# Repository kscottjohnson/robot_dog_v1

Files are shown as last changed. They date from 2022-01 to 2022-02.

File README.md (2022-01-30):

# robot_dog_v1

Robot Dog built with 

Adafruit Feather nRF52840 Sense
https://www.adafruit.com/product/4516

Adafruit 16-Channel 12-bit PWM/Servo Driver
https://www.adafruit.com/product/815

Adafruit PowerBoost 1000
https://www.adafruit.com/product/2465

Adafruit FeatherWing OLED - 128x64 OLED
https://www.adafruit.com/product/4650

Inspired by James Bruton's Mini Robot Dog
https://www.youtube.com/watch?v=DfBF26DaT-M

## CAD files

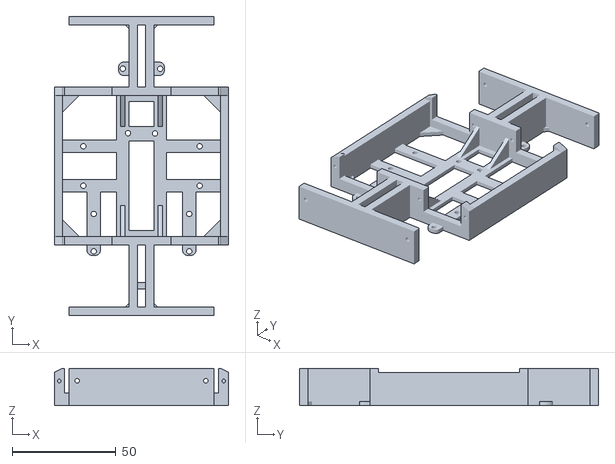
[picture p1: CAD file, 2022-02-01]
stl/chassis.stl
84.0 x 144.0 x 18.0

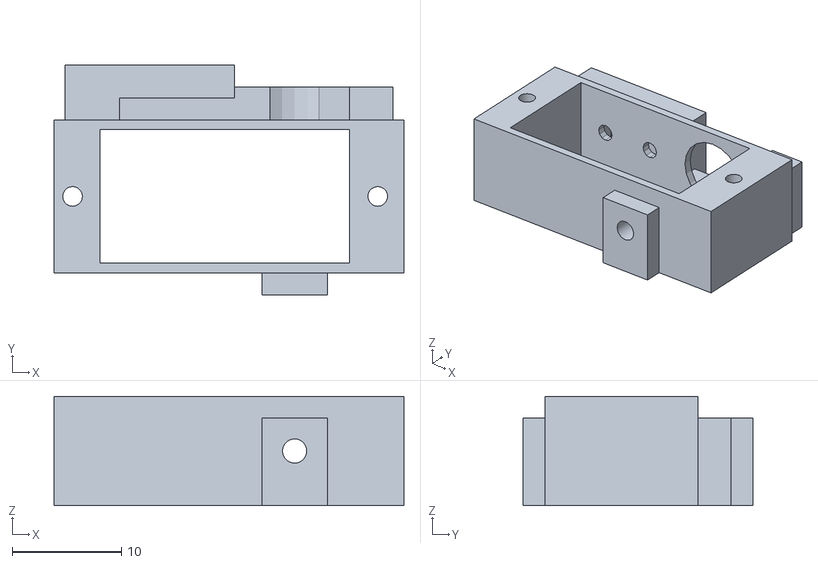
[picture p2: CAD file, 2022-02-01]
stl/shoulder.stl
32.0 x 21.0 x 10.0

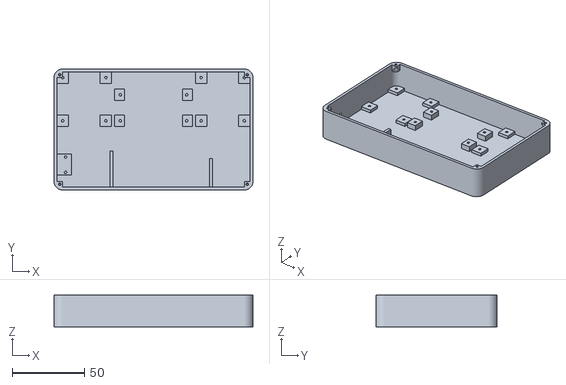
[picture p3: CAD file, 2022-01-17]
stl/remote_case.stl
138.0 x 84.0 x 22.0

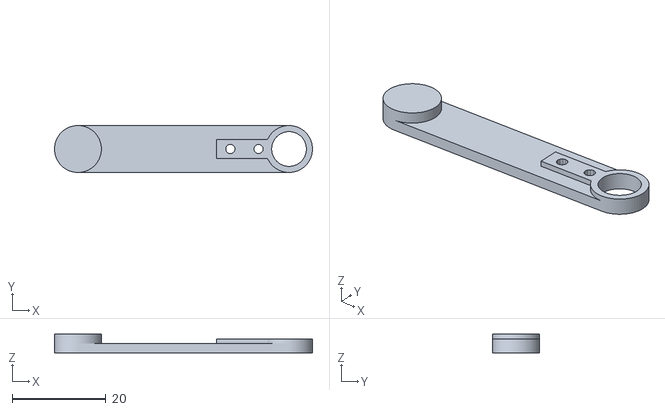
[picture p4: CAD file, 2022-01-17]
stl/leg_lower_no_foot.stl
55.0 x 10.0 x 4.00

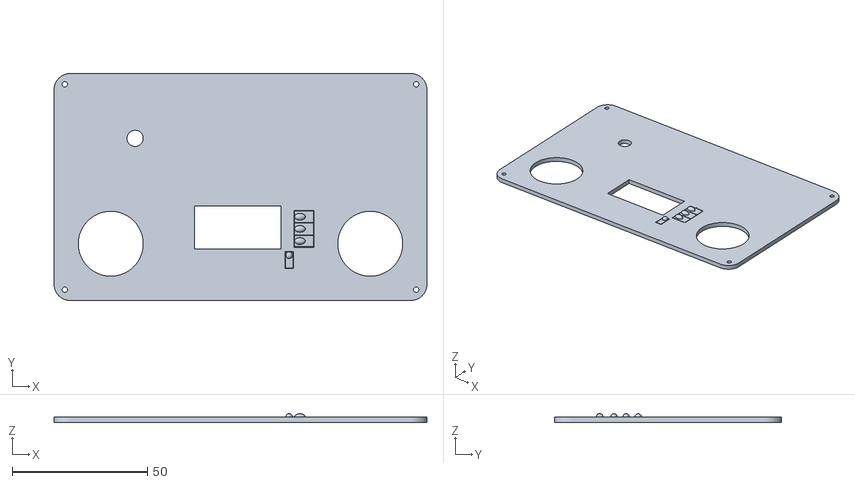
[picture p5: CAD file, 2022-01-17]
stl/remote_lid.stl
138.0 x 84.0 x 3.30

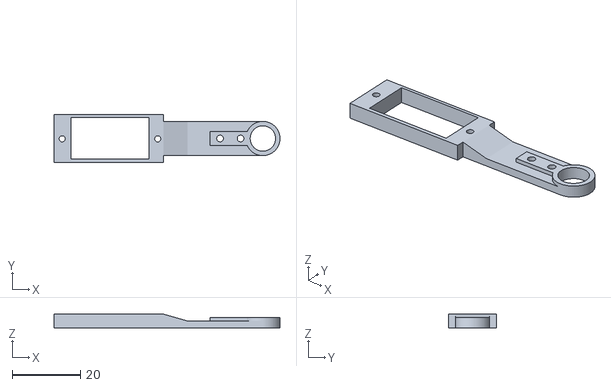
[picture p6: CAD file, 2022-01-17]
stl/leg_upper.stl
66.0 x 14.0 x 4.00

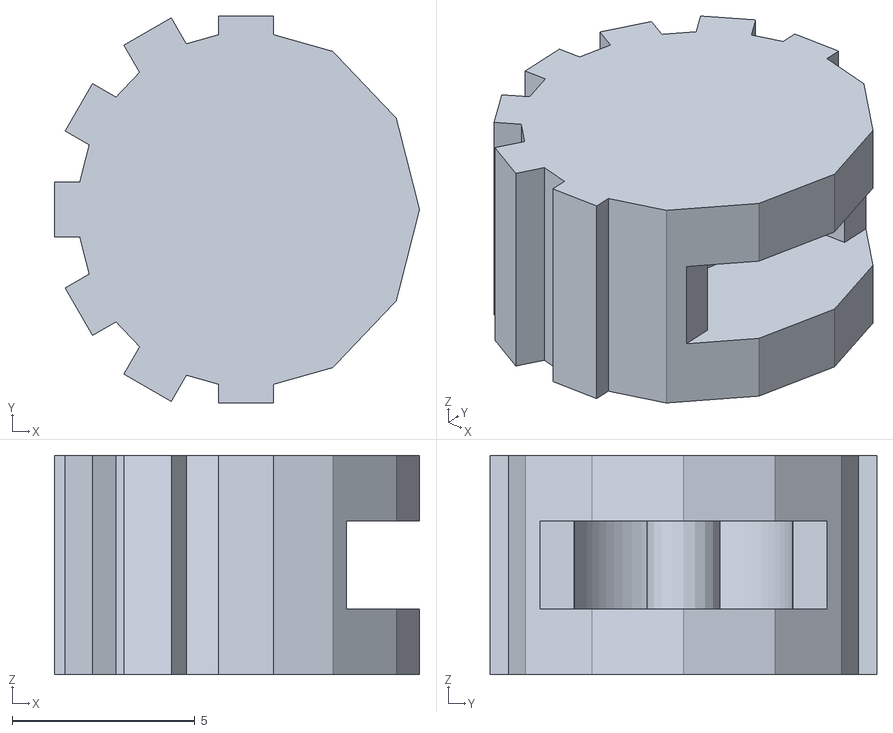
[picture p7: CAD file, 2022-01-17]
stl/foot_flex.stl
10.0 x 10.6 x 6.00

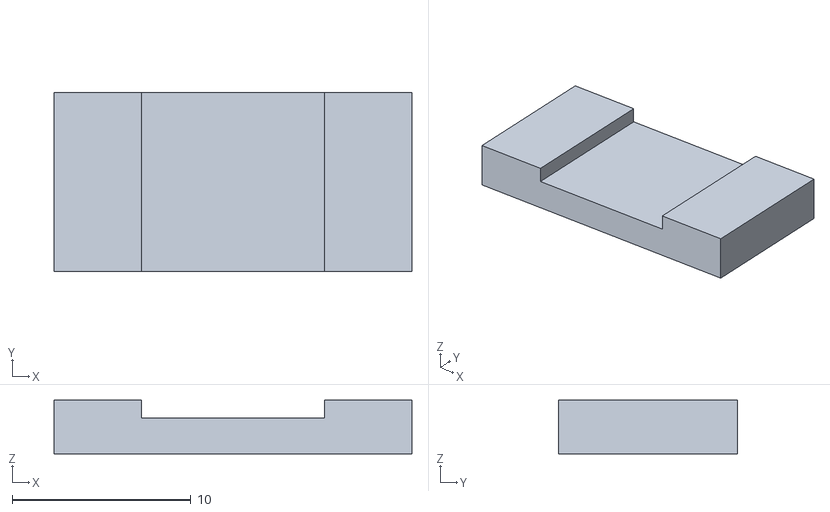
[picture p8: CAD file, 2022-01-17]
stl/leg_lower_holder.stl
20.0 x 10.0 x 3.00

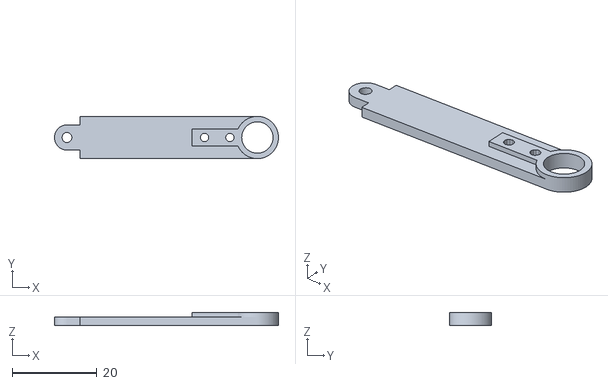
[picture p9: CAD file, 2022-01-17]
stl/leg_lower_w_foot.stl
53.0 x 10.0 x 3.00

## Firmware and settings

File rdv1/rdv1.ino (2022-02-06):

#include <SPI.h>
#include <Wire.h>
#include <Adafruit_GFX.h>
#include <Adafruit_SH110X.h>
#include <bluefruit.h>
#include <Adafruit_PWMServoDriver.h>
#include <Adafruit_LSM6DS33.h>
#include <Adafruit_LIS3MDL.h>
#include <Adafruit_Sensor_Calibration.h>
#include <Adafruit_AHRS.h>
#include "LegServo.h"

// Servos
Adafruit_PWMServoDriver driver = Adafruit_PWMServoDriver(0x40);
#define SERVO_FREQ 50

LegServo servos[12] = {  // 90 degrees 220 to 420; 
  LegServo(&driver,  0, 300, 90), // Front Right
  LegServo(&driver,  1, 243, 45),
  LegServo(&driver,  2, 273, 90),
  LegServo(&driver,  8, 298, 90), // Front Left
  LegServo(&driver,  9, 333, 135),
  LegServo(&driver, 10, 300, 90),
  LegServo(&driver,  4, 306, 90), // Back Right
  LegServo(&driver,  5, 360, 135),
  LegServo(&driver,  6, 300, 90),
  LegServo(&driver, 12, 310, 90), // Back Left
  LegServo(&driver, 13, 242, 45),
  LegServo(&driver, 14, 320, 90)
};

Leg legs[4] = {
  Leg(&servos[0], &servos[1], &servos[2], false, true, false), // Front Right
  Leg(&servos[3], &servos[4], &servos[5], false, false, false), // Front Left
  Leg(&servos[6], &servos[7], &servos[8], true, false, true), // Back Right
  Leg(&servos[9], &servos[10], &servos[11], true, true, true) // Back Left
};

#define FRONT_RIGHT 0
#define FRONT_LEFT 1
#define BACK_RIGHT 2
#define BACK_LEFT 3

// Bluetooth
BLEUart bleuart;
uint8_t controlMsg[6] = {128,128,128,128,0,0};
uint8_t robotMsg[1] = {0};

// LCD
Adafruit_SH1107 display = Adafruit_SH1107(64, 128, &Wire);

// IMU
Adafruit_Sensor_Calibration_SDFat cal;
Adafruit_LSM6DS33 imu;
Adafruit_LIS3MDL mdl;
sensors_event_t accel;
sensors_event_t gyro;
sensors_event_t temp;
sensors_event_t mag; 
float accel_x, accel_y, accel_z;
float gyro_x, gyro_y, gyro_z;
float mag_x, mag_y, mag_z;

// filter
Adafruit_NXPSensorFusion filter;
#define FILTER_UPDATE_RATE_HZ 100

float ahrs_r, ahrs_p, ahrs_y;

#define BUTTON_A  9
#define BUTTON_B  6
#define BUTTON_C  5
#define BATT_PIN A6

uint8_t mode = 0; // 0 demo, 1 static walking, 2 dynamic walking

unsigned long currentMs;
unsigned long prevMs;
unsigned long connectedMs;
unsigned long filterMs;

uint8_t rx, ry, lx, ly;
bool buttonA, buttonB, buttonC, buttonR, buttonL, buttonAR, buttonBR, buttonCR;

uint8_t robotBatt;

float hipAngle[4];
float shoulderAngle[4];
float kneeAngle[4];

#define CHASSIS_L 114
#define CHASSIS_W 62
#define FEMUR 40
#define CLOCK_CYCLE 10

void setup() {
  Serial.begin(115200);
  while (!Serial) yield();
  Serial.println("rdv1");

  pinMode(BUTTON_A, INPUT_PULLUP);
  pinMode(BUTTON_B, INPUT_PULLUP);
  pinMode(BUTTON_C, INPUT_PULLUP);

  setupIMU();

  filter.begin(FILTER_UPDATE_RATE_HZ);

  // start servos
  driver.begin();
  driver.setPWMFreq(SERVO_FREQ);
  
  //setupDisplay();

  delay(500);
  centerServos();
  
  startBleAdv();

  //robotBatt = readBatt();
  
  prevMs = millis();
}

void loop() {
  currentMs = millis();
  if((currentMs - prevMs) < CLOCK_CYCLE) return;
  prevMs = currentMs;

  if(! Bluefruit.Periph.connected()){
    Serial.println("Not Connected");
    centerServos();
    return;
  }
  if((currentMs - connectedMs) < 1000){ // wait a second after connecting
    return;
  }

  getIMUdata();

  if((currentMs - filterMs) > (1000 / FILTER_UPDATE_RATE_HZ)){
    updateFilter();
    filterMs = currentMs;
  }
  
  //Serial.print("Mode "); Serial.print(mode);
  if(mode == 0) moveDemo();
  else if(mode == 1) moveStaticWalk();
  else if(mode == 2) legDemo();

  //robotBatt = smooth(robotBatt, readBatt(), 10);
  //getRemoteTelemetry();
  //refreshDisplay();
  //sendRemoteTelemetry();
}

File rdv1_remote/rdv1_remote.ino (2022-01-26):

#include <SPI.h>
#include <Wire.h>
#include <Adafruit_GFX.h>
#include <Adafruit_SH110X.h>
#include <bluefruit.h>

BLEClientUart clientUart;
uint8_t controlMsg[6] = {128,128,128,128,0,0};
uint8_t robotMsg[5] = {0,0,0,0,0};

Adafruit_SH1107 display = Adafruit_SH1107(64, 128, &Wire);

#define BUTTON_A  9
#define BUTTON_B  6
#define BUTTON_C  5
#define BUTTON_R 10
#define BUTTON_L 11
#define JOYRX A0
#define JOYRY A1
#define JOYLX A2
#define JOYLY A3
#define BATT_PIN A6

uint8_t mode = 0; // 0 demo, 1 static walking, 2 dynamic walking

unsigned long currentMs;
unsigned long prevMs;

//calibration
int lxMin = 935, lxMax = 0, lyMin = 0, lyMax = 936;
int rxMin = 936, rxMax = 0, ryMin = 0, ryMax = 935;

uint8_t lx, ly, rx, ry;
bool buttonA, buttonB, buttonC, buttonR, buttonL;

uint8_t remoteBatt, robotBatt;

void setup() {
  Serial.begin(115200);
  Serial.println("rdv1 Remote");

  pinMode(BUTTON_A, INPUT_PULLUP);
  pinMode(BUTTON_B, INPUT_PULLUP);
  pinMode(BUTTON_C, INPUT_PULLUP);
  pinMode(BUTTON_R, INPUT_PULLUP);
  pinMode(BUTTON_L, INPUT_PULLUP);

  setControls();
  
  setupDisplay();

  startBleScan();

  remoteBatt = readBatt();
  
  prevMs = millis();
}

void loop() {
  currentMs = millis();
  if(currentMs - prevMs < 50) return;
  prevMs = currentMs;

  if(!digitalRead(BUTTON_A)){
    if(++mode == 3) mode = 0; // cycle mode
    while(!digitalRead(BUTTON_A)){ // pause until button released
      delay(100);
    }
  }

  setControls();

  sendControls();

  remoteBatt = smooth(remoteBatt, readBatt(), 10);
  
  refreshDisplay();
}

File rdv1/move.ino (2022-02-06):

// Leg movement and walking algorithms

void moveLeg(int legNum, float x, float y, float z, float roll, float pitch, float yaw) {
  Leg* leg = &legs[legNum]; 
  //Serial.print("Leg "); Serial.println(legNum);

  // roll adjust 
  float rollZAdj = CHASSIS_W / 2.0 * sin(roll * DEG_TO_RAD);
  if(legNum == 0 || legNum == 2){ // right legs
    z += rollZAdj;
  }
  else{
    z -= rollZAdj;
  }

  // pitch adjust 
  float pitchZAdj = CHASSIS_L / 2.0 * sin(pitch * DEG_TO_RAD);
  //Serial.print(pitchZAdj);Serial.print(" ");
  if(legNum == 0 || legNum == 1){ // front legs
    z += pitchZAdj;
  }
  else {
    z -= pitchZAdj;
  }
  //Serial.println(z);

  if(leg->isReversed()) { // flip y and pitch if leg is reversed
    y *= -1;
    pitch *= -1;
  }
  
  // get leg length on X plane
  float legLenX = sqrt(x*x+z*z);

  // get hip rotation
  float hipAngle = 90;
  if(x != 0){ // check for zero x and set angle otherwise
    hipAngle = acos((legLenX*legLenX+x*x-z*z)/(2*x*legLenX))*RAD_TO_DEG;
  }
  hipAngle += roll; // add roll degrees

  // get leg length on Y plane
  float legLenY = sqrt(y*y+legLenX*legLenX);

  // get shoulder rotation due to y
  float s1 = 90;
  if(y != 0){
    s1 = acos((legLenY*legLenY+y*y-legLenX*legLenX)/(2*y*legLenY)) * RAD_TO_DEG;
  }

  // shoulder and knee given Y leg length
  float s2 = acos((legLenY*legLenY)/(2*FEMUR*legLenY)) * RAD_TO_DEG;
  float kneeAngle = 180 - (180 - 2 * s2);

  //Serial.print(s1);Serial.print(" ");Serial.print(s2);Serial.print(" ");Serial.println(pitch);
  float shoulderAngle = s1+s2+pitch;

  //Serial.print("Angles: ");
  //Serial.print(hipAngle); Serial.print(" ");
  //Serial.print(shoulderAngle); Serial.print(" ");
  //Serial.println(kneeAngle); 
  
  leg->setAngles(hipAngle, shoulderAngle, kneeAngle);
}

void centerServos() {
  legs[FRONT_RIGHT].setDefault();
  legs[FRONT_LEFT].setDefault();
  legs[BACK_RIGHT].setDefault();
  legs[BACK_LEFT].setDefault();
}

void moveDemo(){
  
  //Serial.println("--------Demo");

  //map left y axis to z hight
  //Serial.print(ly); Serial.print(" ");
  float newZ = map(ly, 0, 255, 36, 75);
  //Serial.println(newZ);

  //map left x axis to y forward/backward
  //Serial.print(lx); Serial.print(" ");
  float newY = map(lx, 0, 255, 15, -15);
  //Serial.println(newY);

  float newR = 0;
  //map right x axis to roll
  //Serial.print(rx); Serial.print(" ");
  newR = map(rx, 0, 255, 30, -30);
  //Serial.println(newR);

  float newX = 0;
  //map right x axis to x adjust
  //Serial.print(rx); Serial.print(" ");
  //newX = map(rx, 0, 255, -10, 10);
  //Serial.println(newX);

  //map right y axis to pitch
  //Serial.print(ry); Serial.print(" ");
  float newP = map(ry, 0, 255, 20, -20);
  //Serial.println(newP);

  moveLeg(FRONT_RIGHT, newX, newY, newZ, newR, newP, 0);
  moveLeg(FRONT_LEFT , newX, newY, newZ, newR, newP, 0);
  moveLeg(BACK_RIGHT , newX, newY, newZ, newR, newP, 0);
  moveLeg(BACK_LEFT  , newX, newY, newZ, newR, newP, 0);
}

// static walk global vars
const int8_t sWalkX[] =       {  0,  0,  0,  0,  0,  0,  0,  0,   0,  0,  0,  0,  0,  0,  0,  0};
const int8_t sWalkY[] =       {-15,  0, 15, 10,  5,  0, -5,-10, -15,  0, 15, 10,  5,  0, -5,-10};
const int8_t sWalkZ[] =       { 56, 52, 56, 56, 56, 56, 56, 56,  56, 52, 56, 56, 56, 56, 56, 56};
const int8_t sWalkXright[] =  { -6,  0,  6,  4,  2,  0, -2, -4,  -6,  0,  6,  4,  2,  0, -2, -4};
const int8_t sWalkXleft[] =   {  6,  0, -6, -4, -2,  0,  2,  4,   6,  0, -6, -4, -2,  0,  2,  4};
const int8_t sMaxSpeed = 4;
int8_t sWalkSpeed; // cycles per second
int8_t sSteer; // 1=right, 0=none, -1=left
const float sSpinX[4][8] = {{-10.4,  0.0,  9.4,  6.4,  3.3,  0.0, -3.4, -6.8},
                            {  3.4,  0.0, -3.3, -6.4, -9.4,  0.0, 10.4,  6.8},
                            {-10.4, -6.8, -3.4,  0.0,  3.3,  6.4,  9.4,  0.0},
                            {  3.4,  6.8, 10.4,  0.0, -9.4, -6.4, -3.3,  0.0}};
const float sSpinY[4][8] = {{  4.5,  0.0, -6.2, -4.0, -1.9,  0.0,  1.7,  3.2},
                            {  1.7,  0.0, -1.9, -4.0, -6.2,  0.0,  4.5,  3.2},
                            { -4.5, -3.2, -1.7,  0.0,  1.9,  4.0,  6.2,  0.0},
                            { -1.7, -3.2, -4.5,  0.0,  6.2,  4.0,  1.9,  0.0}};
const float sSpinZ[4][8] = {{ 56.0, 52.0, 56.0, 56.0, 56.0, 56.0, 56.0, 56.0},
                            { 56.0, 56.0, 56.0, 56.0, 56.0, 52.0, 56.0, 56.0},
                            { 56.0, 56.0, 56.0, 56.0, 56.0, 56.0, 56.0, 52.0},
                            { 56.0, 56.0, 56.0, 52.0, 56.0, 56.0, 56.0, 56.0}};
int8_t sTicksPerState;
int8_t sTick = 0;
int8_t sWalkState;
float sCurrentX[4], sCurrentY[4], sCurrentZ[4];
float    sPrevX[4],    sPrevY[4],    sPrevZ[4];
const uint8_t legOrder[4] = {2,0,3,1};
bool sFirstStep = true;
int8_t sDirection = 1; // 1 forward, -1 reverse
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

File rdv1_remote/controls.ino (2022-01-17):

void setControls() {
  lx = normalizeJoy(analogRead(JOYLX), 0, lxMin, lxMax);
  ly = normalizeJoy(analogRead(JOYLY), 0, lyMin, lyMax);
  rx = normalizeJoy(analogRead(JOYRX), 0, rxMin, rxMax);
  ry = normalizeJoy(analogRead(JOYRY), 0, ryMin, ryMax);

  controlMsg[0] = lx;
  controlMsg[1] = ly;
  controlMsg[2] = rx;
  controlMsg[3] = ry;

  buttonA = !digitalRead(BUTTON_A);
  buttonB = !digitalRead(BUTTON_B);
  buttonC = !digitalRead(BUTTON_C);
  buttonL = !digitalRead(BUTTON_L);
  buttonR = !digitalRead(BUTTON_R);

  controlMsg[4] = 0;
  if(buttonA) controlMsg[4] += 1;
  if(buttonB) controlMsg[4] += 2;
  if(buttonC) controlMsg[4] += 4; 
  if(buttonL) controlMsg[4] += 8;
  if(buttonR) controlMsg[4] += 16;

  controlMsg[5] = mode;
}

uint8_t normalizeJoy(int input, int flip, int min, int max){
  return constrain(map(input, min, max, 0, 255), 1, 255);
}

uint8_t readBatt() {
  float volts = analogRead(BATT_PIN) * 2.0 * 3.3 / 1024.0;
  return (volts * volts * -2.9487 + volts * 25.0447 - 52.1712) * 200;
}

uint8_t smooth(uint8_t oldValue, uint8_t newValue, uint8_t factor) {
  return (oldValue * factor + newValue) / (factor + 1);
}

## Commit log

2022-01-17 initial upload of files
    [remote cover.3mf]
2022-01-17 .stl file upload
    [chassis.stl, foot_flex.stl, leg_lower_holder.stl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]
2022-01-19 changed to new chassis configuration
2022-01-25 reversed back legs
2022-01-26 completed pitch and roll
2022-01-31 updated leg calibration
2022-02-01 added steering while walking
2022-02-01 added horn to hip servo
    [chassis.stl, shoulder.stl]
2022-02-01 added imu lib and serial debug
2022-02-04 updated calibration
2022-02-05 added IMU calibration
2022-02-05 added calibration write script
2022-02-06 added AHRS filter
2022-02-06 dynamic leg left demo
